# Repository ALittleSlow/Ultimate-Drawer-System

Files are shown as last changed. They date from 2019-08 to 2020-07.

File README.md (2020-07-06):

# Ultimate-Drawer-System
Intended to be the ultimate drawer system that is
* backwards-compatible with MarcElbichon's Ultimate Drawer System
* printable with FDM printing
* optimizable for anything you store in drawers
* compatible with Thingiverse's Customizer
* written for ease of improvement (which could use some improvement)

## The System
* Drawers and complementary shelving units are sized in units called "Us".
* If only one dimension is given, it is assumed to be the height and the width and depth are assumed to be 1U.
* A 1U drawer is 120 mm wide by 120 mm deep by 19 mm high.
* A 2U drawer is 120 mm wide by 120 mm deep by 39 mm high.
* Actual drawer width is 131 * Us wide - 10 mm
* Actual drawer depth is 130 * Us deep - 10 mm
* Actual drawer height is 20 * Us high - 1 mm
* A 2U shelf (or cabinet) is 131 mm wide by 130 deep by 50 mm high. (You can't (currently) make a 1U shelf.)
* Walls are 5 mm (W_t). Slots are 20 mm apart. 0.5 mm gap (g) between side wall and drawer. 
  So the height of a shelf is U.z*(19+1)+W_t*2 = 20U.z+10, width is U.x*120+5*2+1, depth is U.y*120+5*2.
* A double-wide shelf (2-U.x), to stack nicely with a single wide, should be 
  120U.z+11. With 5 mm walls, 2*(120+11)=D.x+2*W_t+2*g=D.x+11 => D.x (2U drawer width) = 262 - 11 = 251.
* A one-and-a-half wide drawer is (1.5-U.x) is 131+65.5 = 196.5-11 = 185.5.

### Inserts
Trays that fit inside basic drawers. 
Inside dimensions of 1U drawer: 131-10-1-2=118 wide, 120-2 deep, 18 high, 3 mm corner radius
Inside dimensions of 1.5U wide drawer =195.5-10-1-2 = 182.5
Inside dimensions of 2 wide drawer: 262-13 = 249
Inside dimensions of 1.5U deep drawer =195-10-2 = 183
Inside dimensions of 2 deep drawer: 260-10-2 = 247
I think the least common denominator of those widths is 0.5 mm, and 1 mm for depth. 1 mm for height also, since heights are 19, 39, 59, etc.

## Printing
Because it has all the features, is small, and is still usable, [this is a good test model](https://github.com/ALittleSlow/Ultimate-Drawer-System/blob/master/examples/shelf%200.5Wx0.5Dx2H%20clips%20noLock%20rearWeak%20frontStrong%20tol0.4.stl).

## Contributors and Contributing
This is an OpenSCAD copy then enchancement of [The Ultimate Drawer System by MarcElbichon](https://www.thingiverse.com/thing:2302575) and others to come. Contributors are welcome.

## License
This work is originally licensed under the Creative Commons Attribution-NonCommercial-ShareAlike 4.0 (CC-BY-NC-SA 4.0) but may be distributed under the GPLv3 in accordinance with the former's one-way GPLv3 compatibility declaration.

## Features
Compared to MarcElbichon's version
* Produces faithful replicas
* Add an ergonomic drawer pull
* Adds a drawer locking mechanism
* Adds a stops to help keep drawers from pulling all the way out (needs testing)
* Adds 1.5U and 2U widths and depths to the standard 1U width and 1U depth.
* The option to clip shelving units together instead of (or in addition to) screwing them together.

## Roadmap
Planned enhancements include (in no particular order)
* Drawers with dividers
* Handles for portable storage units
* Bumpers for increased ruggedness
* Sturdier versions of the drawers for increased ruggedness
* Custom label inserts
* Bosses and recesses to aid in stacking units

## Coding conventions
* Generally follow OpenSCAD conventions
* Customerizer parameters capitalized first letters with words separated by underscores.

## More information
You may find additional information, discussion, and resources at
* (Thingiverse drawer)[https://www.thingiverse.com/thing:2302575]
* (Thingiverse shelf)[https://www.thingiverse.com/thing:3796410]
* (Thingiverse MarcElbichon version)[https://www.thingiverse.com/thing:2302575]
* (Parametric drawers by _WG_)[https://www.thingiverse.com/thing:2552468]

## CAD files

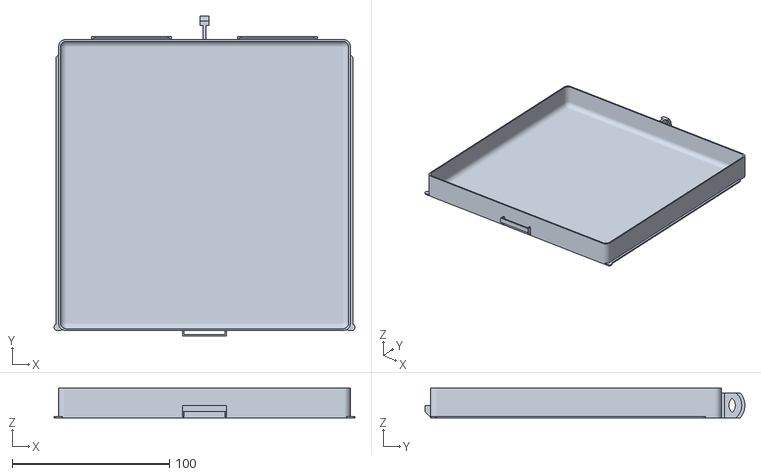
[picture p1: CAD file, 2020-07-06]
examples/drawer 1.5Wx1.5Dx1H ergo catch lock.stl
191.5 x 203.5 x 19.0

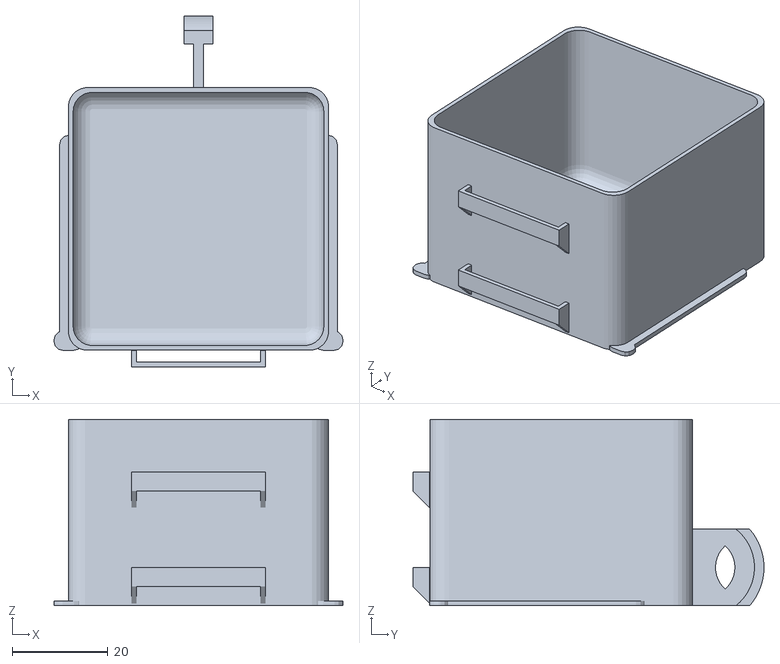
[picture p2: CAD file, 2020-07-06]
examples/drawer 0.5Wx05.Dx2H ergo catch noLock.stl
60.5 x 73.5 x 39.0

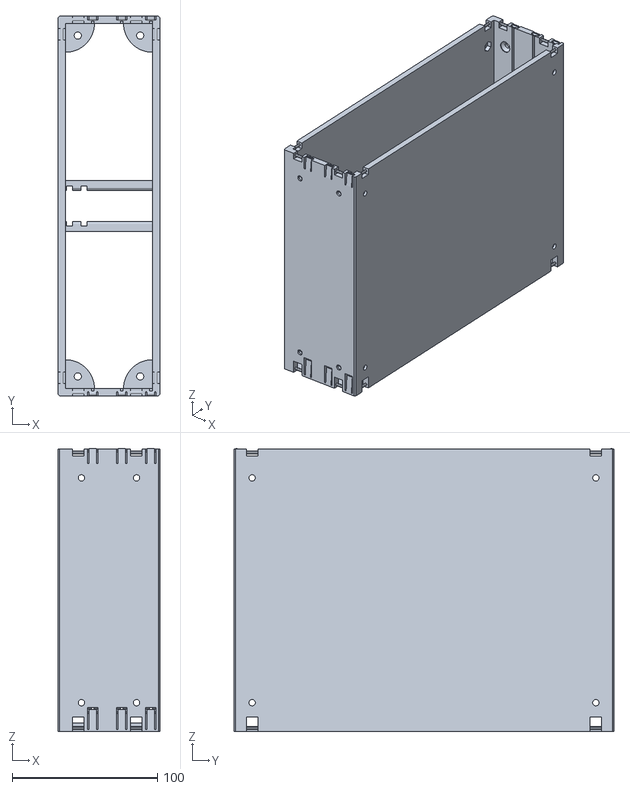
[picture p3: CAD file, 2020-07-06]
examples/shelf Becky's Jewelry Box 2x1.5x3.stl
70.0 x 262.0 x 195.4

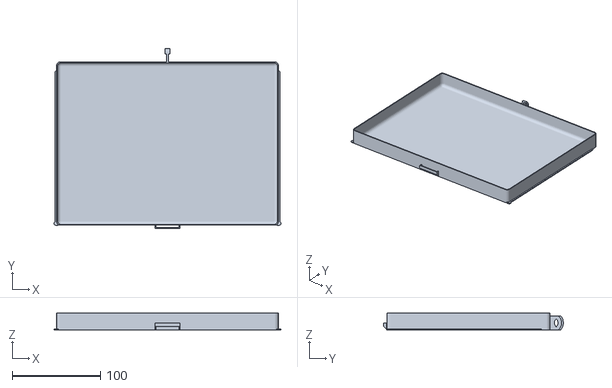
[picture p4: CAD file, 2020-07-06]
examples/drawer 1.5Wx2Dx1H ergo catch lock.stl
257.0 x 203.5 x 19.0

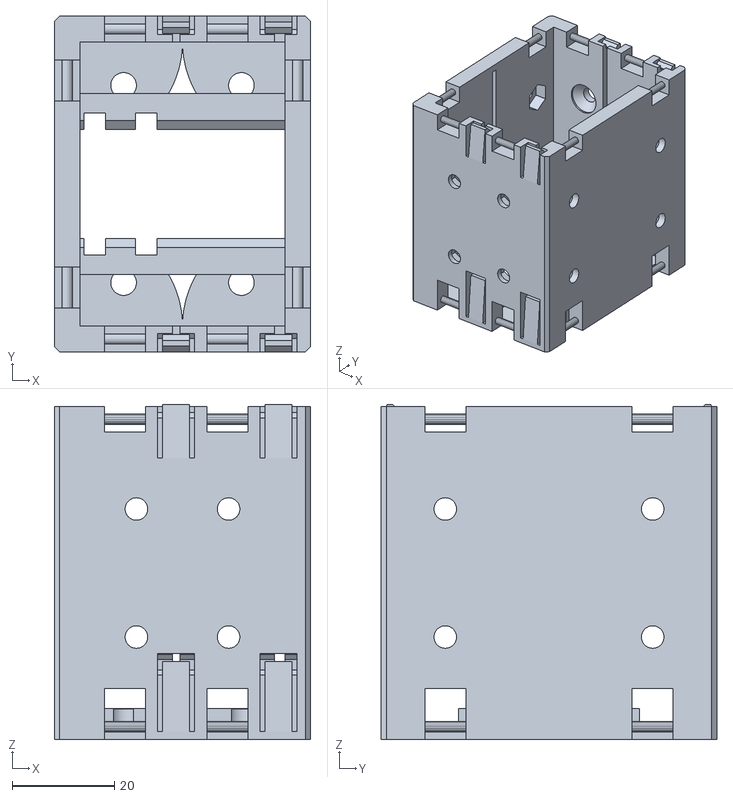
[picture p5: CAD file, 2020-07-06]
examples/Shelf Test Mini Model v1.1.stl
50.0 x 65.5 x 65.4

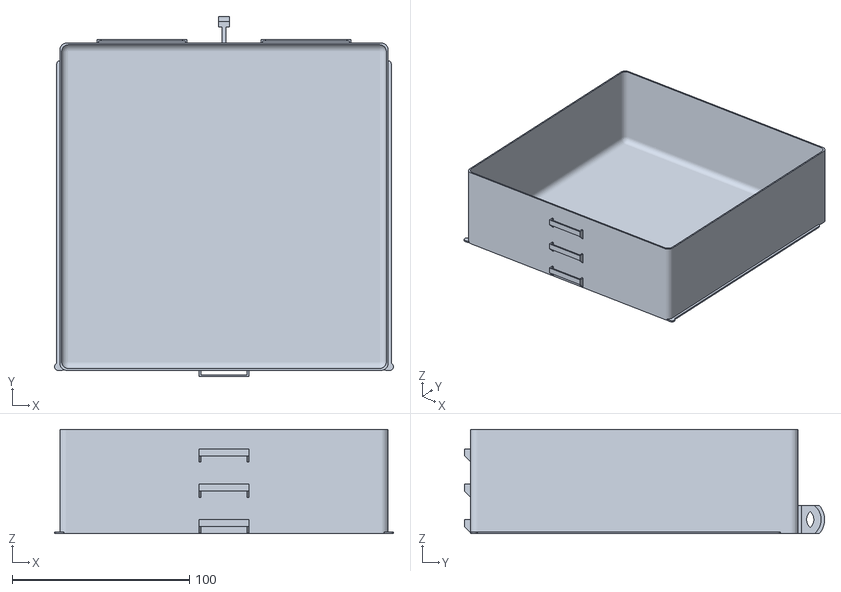
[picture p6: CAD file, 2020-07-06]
examples/drawer 1.5Wx1.5Dx3H ergo catch lock.stl
191.5 x 203.5 x 59.0

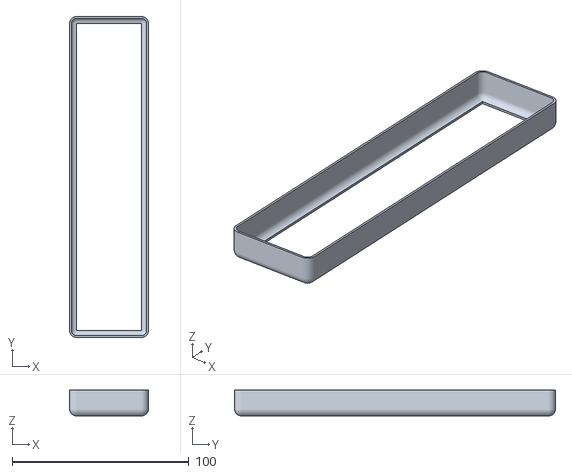
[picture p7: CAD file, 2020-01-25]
examples/insert 45x118 x15for eye glasses.stl
44.6 x 181.6 x 14.6

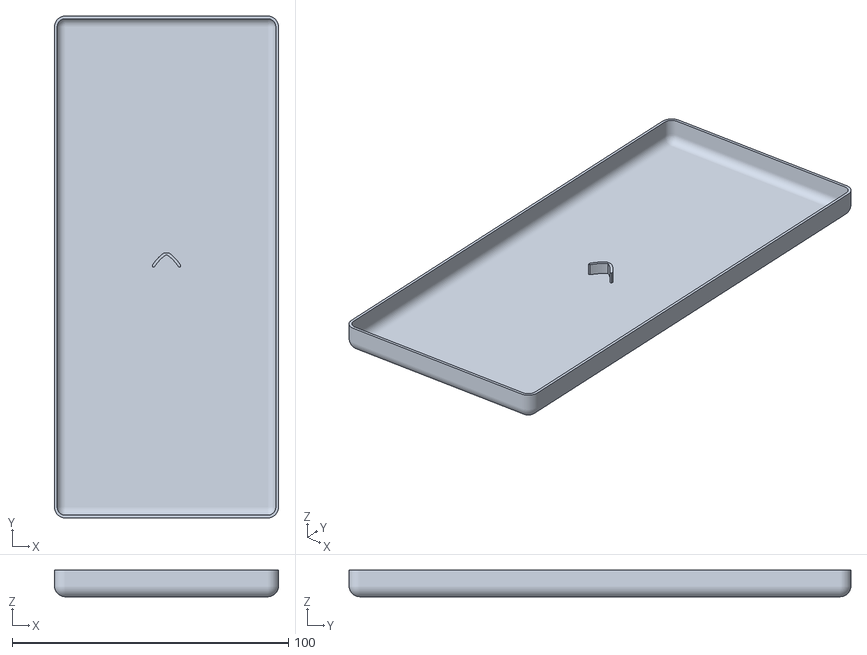
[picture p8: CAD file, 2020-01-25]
examples/insert 182x81.5x10 pliers.stl
81.1 x 181.6 x 9.60

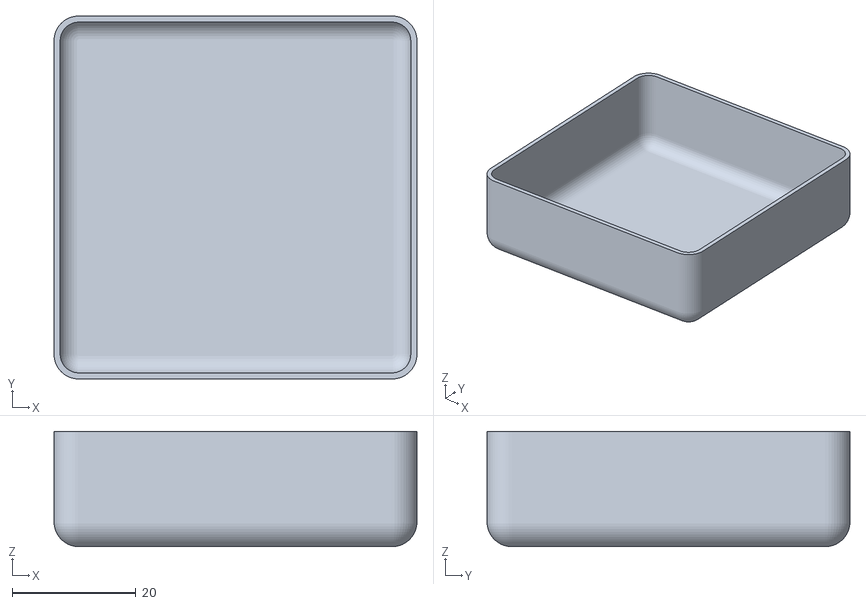
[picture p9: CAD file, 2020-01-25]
examples/insert 59x59x19 for 1x1x1 or 1x1x2 drawer.stl
58.6 x 58.6 x 18.6

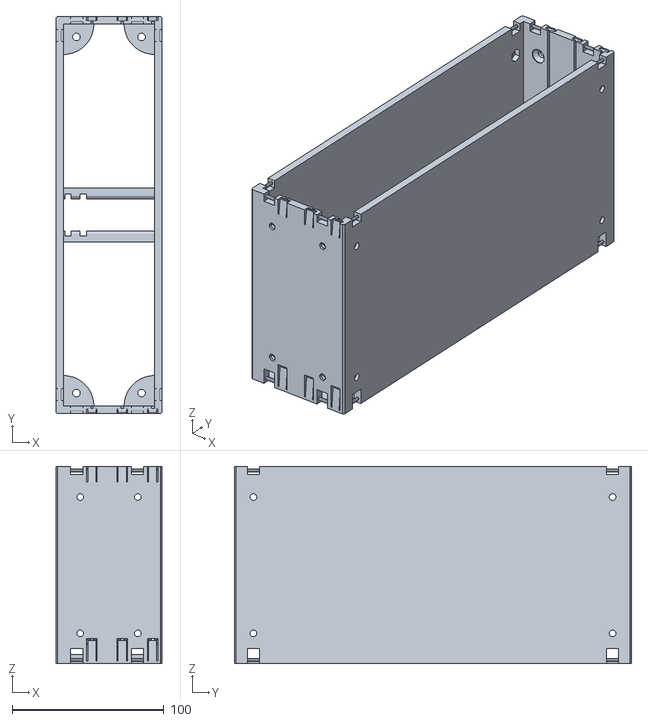
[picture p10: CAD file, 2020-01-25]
examples/shelf Becky's Jewelry Box shelf 2x1x3.stl
70.0 x 262.0 x 130.3

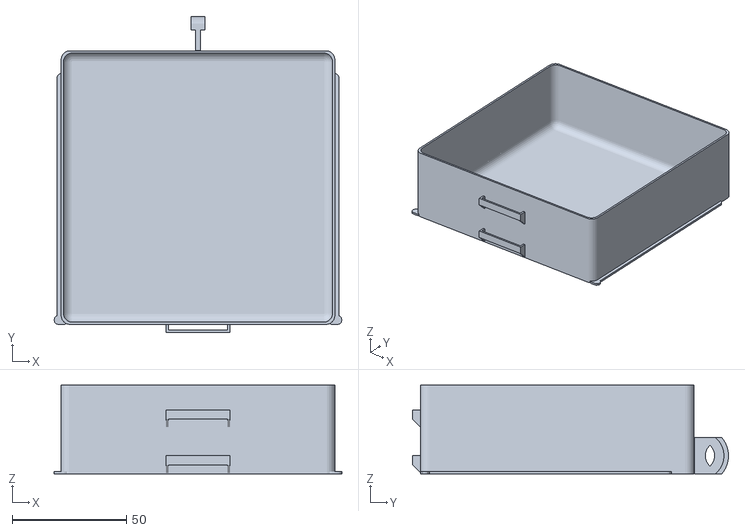
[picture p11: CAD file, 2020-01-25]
examples/drawer 1Wx1Dx2H ergo catch lock noLabel.stl
126.0 x 138.5 x 39.0

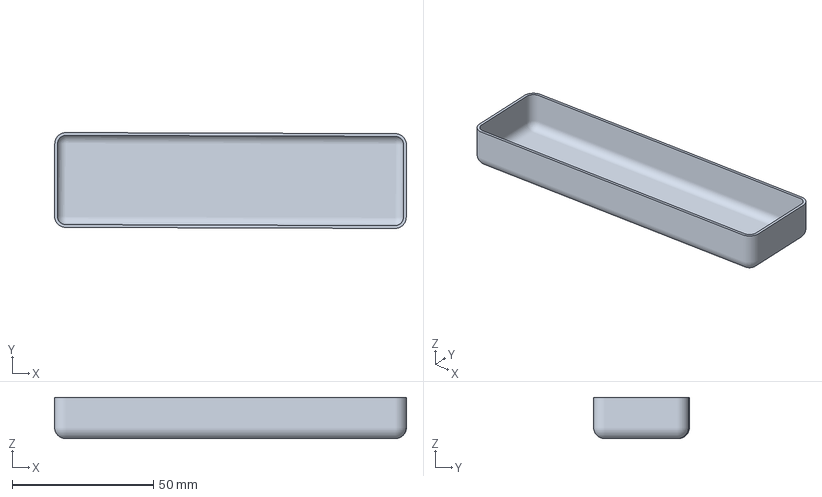
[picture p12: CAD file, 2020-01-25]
examples/insert Elmers Glue Stick 40g.3mf
124.7 x 34.0 x 14.6 mm

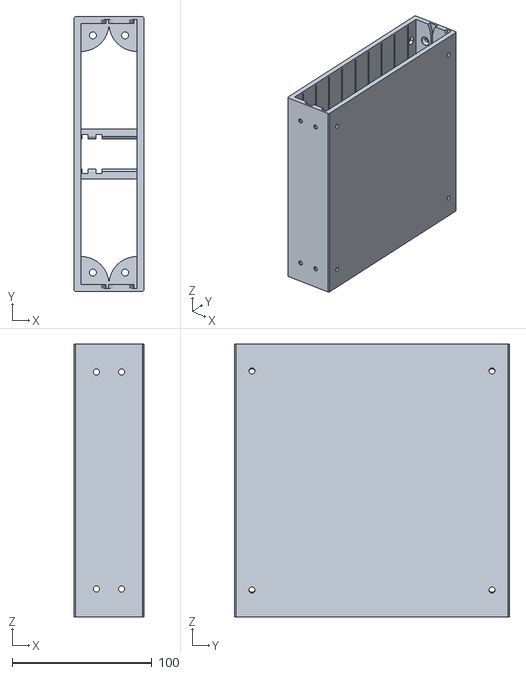
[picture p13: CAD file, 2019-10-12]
examples/shelf 2U1.5D1.5W.stl
50.0 x 196.5 x 195.0

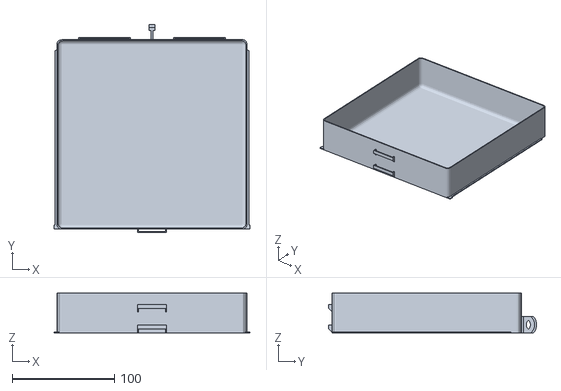
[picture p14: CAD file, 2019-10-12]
examples/drawer 1.5Wx1.5Dx2U ergo catch lock.stl
191.5 x 203.4 x 39.0

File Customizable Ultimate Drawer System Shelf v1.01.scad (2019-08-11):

// Customizable Ultimate Drawer System Shelf
// Remixed from MarcElbichon's Ultimate Drawer System https://www.thingiverse.com/thing:2302575 (CC-BY 4.0)
// Copyright (C) 2019 by Brian Alano (and possibly others)
// Licensed under the Creative Commons Attribution-NonCommercial-ShareAlike 4.0 (CC-BY-NC-SA 4.0) and
// sharable under the GPLv3.

/* Release Notes
 * Version 1.01 - bugfix release
 * Fix bug in clips where variable was undefined
 * Remove non-functional "retaining clip" parameter
 */ 

/* Design notes
// width is x dimension, across the face of the drawer
// depth is y dimension, front to back of the drawer
// height is z dimension
*/

/* Coding Style Guide 
 * User parameters and modules use underscores between words.
 * Other variable names use camel case.
 * Separate features into their own modules if they are more than a couple lines long.
 * All dimensions should be assigned to variables, usually global ones so they can be found easily.
 * Keep local modules local.
 * Keep local variables local.
 * Maintain Thingiverse Customizer compatibility.
 * Maintain backwards compatibility with MarcElbichon's Ultimate Drawer System 
   (https://www.thingiverse.com/thing:2302575). This means a 1Ux1Ux1U drawer 
   made with this program will work in MarcElbichon's shelf. 
 * Whereas normally an "include" file would handle parameters that are reused among code, 
   Customizer can't handle that. Instead we'll have to manually paste in the include file whenever it changes.
*/

// Walls are 5 mm (W_t). Slots are 20 mm apart. 0.5 mm gap (g) between side wall and drawer. 
// So the height of a shelf is U.z*(19+1)+W_t*2 = 20U.z+10, width is U.x*120+5*2+1, depth is U.y*120+5*2.
// A double-wide shelf (2-U.x), to stack nicely with a single wide, should be 
// 120U.z+11. With 5 mm walls, 2*(120+11)=D.x+2*W_t+2*g=D.x+11 => D.x (2U drawer width) = 262 - 11 = 251.
// A one-and-a-half wide drawer is (1.5-U.x) is 131+65.5 = 196.5-11 = 185.5.
//which part to render

//TO-DO add stacking aligners

/* [General] */
// which part of the shelf to render. Customizer will generate one of each.
part="shelf"; //[shelf, clip, rear_lock] 
//one U wide is 131 mm. Total width is 131*U.
U_Wide=1; //[1,1.5,2]
//one U high 20 mm for the drawer and 10 mm for the shelf, or 30 mm. In general, total height is 20*U + 10.
U_High=2; //[2:15]
//one U deep is 130 mm. Total depth is 130*U.
U_Deep=1; //[1,1.5,2]
/* [Features] */
// enable using clips to hold shelves together [not implemented]
clips="no"; // [yes, no]
// add a drawer locking mechanism in the rear?
rear_lock="no"; // [yes, no]
/* [Rendering] */
// 3d printing layer height (optimizes some spacing
layer_height = 0.2; // [0.1:0.05:0.3]
// set this to printing before pressing Create Thing for best results
orientation = "printing"; // [printing, viewing]
/* [Advanced] */
/* [Hidden] */
hole_diameter=5;
backThickness=2;

//shelfWidth = 131;
//shelfDepth = 130; //z direction
wallThickness = 5;
shelfUnit = [130, 131, 30];
shelf = [shelfUnit.x * U_Deep, shelfUnit.y * U_Wide, (shelfUnit.z - wallThickness*2) * U_High + wallThickness*2];
shelfCut = [shelf.x, shelf.y - wallThickness*2, shelf.z - wallThickness*2];
/* We want 1 - 2W shelf to be the same dimension as 2 - 1W shelves. This means the drawer will be wider than 120*2 since there are no walls in between. Similarly, we want 2 - 1.5W shelves to be the same dimension as 3 - 1W shelves.
    so
    1W = 131 shelf, 131-10 = 121 cut, 131-11 = 120 drawer
    1.5W=131+65.5=196.5shelf,186.5cut,196.5-11=185.5drawer
    2W = 262 shelf, 262-10 = 252 cut, 262-11 = 251 drawer
    1D = 130 shelf, 130  = 130 cut, 130-10 = 120 drawer
    2D = 260 shelf, 260  = 260 cut, 260-10 = 250 drawer
    1U = (30-walls)*U+walls=30 shelf, 30-10  =  20 cut, 30-10-1=  19 drawer
    2U =  50 shelf, 50-10  =  40 cut, 50-10-1=  39 drawer
    W=
    Front to back we can do the same thing, though it's less useful.
   The same does not apply to the height. 2 - 2U shelves will be 100mm, but 1 - 4U shelf is only 90mm.
*/    

tolerance = 0.2;
slotSpacing = shelfUnit.z - wallThickness*2;

rearLockSlot = [3.5, 26, 8]; // copied from the drawer as a reference dimension
rearLockWallThickness = 1;
// tab is "tongue" part of the rear latch mechanism
tabSize = [1.5, rearLockSlot.y - rearLockWallThickness*2 - tolerance,
    rearLockSlot.z]; 
// bar is the main part of the rear_lock mechanism
barSize = [6.5 - tolerance, tabSize.y, slotSpacing];
snapHead = 4.4;
snapInset = 3;

holeOffset = [20, 12.5, 16]; // positions of the holes from the outside edges of the respective sides
slotBottomWidth = 1.25;
slotSideLength = shelfCut.x - 18;
slotTaperLength = 15;
clipCut = [10, 5, 8];
clip_bar_diameter = 2;
clipThickness = 1.2;
slotDepth = 3;

// Convenience definitions
X = [1, 0, 0]; // x-coordinate unit vector 
Y = [0, 1, 0]; // y-coordinate unit vector 
Z = [0, 0, 1]; // y-coordinate unit vector 
epsilon = 0.01; // mainly used to avoid non-manifold surfaces

$fa=1;
$fs=.4;


//module shelf() {
//    module add() {
//    }
//    module subtract() {
//    }
//    difference() {
//    }
//
//}

// the spacing between drawings is 20, or unit.z + 1. so a 1U drawer is 19, a 2U drawer is 39, etc.
function zU(u) = slotSpacing * u - 1;

// extrude a given length of rear latch bar
module bar_stock(h) {
     reflect(Y) // double the profile half
        linear_extrude(h) 
        polygon([
            [-epsilon, epsilon], [-epsilon, -barSize.y/2],
            [1.35, -barSize.y/2],
            [barSize.x/2, -(barSize.y/2 - barSize.x/2 + 1.35)],
            [barSize.x - 1.35, -barSize.y/2],
            [barSize.x, -barSize.y/2],
            [barSize.x, epsilon]
        ]);
}

module shelf() {
    //yOffset = 13; // for the front latch. Needs work. wide enough to clear any drawer pulls. Otherwise as narrow as possible.
    topSlotSpacing = 20.17; // measured from the original
 
    // h - height of inside of shelf
    // w - weidth of inside of shelf

    // make one of four wall mount plates for the back wall
    module back() {
        r= slotSpacing;
        offset=holeOffset.z - hole_diameter/2;
        module add() {
            translate([wallThickness, wallThickness])
                rotate_extrude2(angle=90)
                square(size=[r, backThickness]);
        }
        module subtract() {
            translate([offset, offset]) 
                cylinder(d=hole_diameter, h=backThickness*4, center=true);
        }
        rotate([0, -90, 0]) // move it from the XY to YZ plane
            difference() {
                add();
                subtract();
        }
    }

    module countersink() {
        counterbore_h = 0.5;
        countersink_h = 2.3;
        counterbore_d = 9;
        through_d = 4.4;
        // counterbore
        translate([0, 0, -epsilon]) cylinder(d=counterbore_d, h=counterbore_h + epsilon*2);
        // countersink
        translate([0, 0, counterbore_h]) cylinder(d1=counterbore_d, d2=through_d, h=countersink_h);
        // through
        translate([0, 0, counterbore_h + countersink_h - epsilon]) cylinder(d=through_d, h=wallThickness);
    }

    module hex_hole() { 
        hex_w = 7.4;
       
        hex_h = 3.5;
        through_h = 1.5;
        through_d = 4.4;
        // hex head
        boxWidth = hex_w/1.75;
        translate([0, 0, hex_h/2-epsilon])
            for (r = [-60, 0, 60])
                rotate([0,0,r])
                cube([boxWidth, hex_w, hex_h+epsilon*2], true);
        // through hole
        translate([0, 0, hex_h - epsilon])
            cylinder(d=through_d, h=through_h + epsilon*2);
    }
    // make the slot and catch that the rear slot slides into
    module rear_slot() {
        blockSize = [barSize.x, barSize.y + tabSize.y/2, shelfCut.z];
        
        // add a block of material to enclose the slot
        module add() {
            translate([-shelf.x/2 + blockSize.x/2, 0, 0])
                cube(blockSize, center=true);
        }
        
        module subtract() {
            // detents for the snap
            reflect(Y) {
                translate([-shelf.x/2 + blockSize.x/2 , barSize.y/2]) {
                    // one to hold it up
                    translate([0, 0, shelf.z/2 - slotSpacing/2 + snapHead/2])
                        cube([blockSize.x + epsilon *2, snapHead, snapHead], center=true);
                    // one to hold it down
                    translate([0, 0, shelf.z/2 - slotSpacing + snapHead/2])
                        cube([blockSize.x + epsilon *2, snapHead, snapHead], center=true);
                }
            }
        }
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

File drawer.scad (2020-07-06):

// Customizable Ultimate Drawer System Drawer
// Remixed from MarcElbichon's Ultimate Drawer System https://www.thingiverse.com/thing:2302575 (CC-BY 4.0)
// Copyright (C) 2019 by Brian Alano (and possibly others)
// Licensed under the Creative Commons Attribution-NonCommercial-ShareAlike 4.0 (CC-BY-NC-SA 4.0)

/* Release Notes 
 * Version 1.1
 * Made label slots optional, and removed them entirely for 0.5U wide drawers.
 * Added 0.5U wide and 0.5U deep options
 */
 
/* Design notes
// width is x dimension, across the face of the drawer
// depth is y dimension, front to back of the drawer
// height is z dimension
*/

/* Coding Style Guide 
 * User parameters and modules use underscores between words.
 * Other variable names use camel case.
 * Separate features into their own modules if they are more than a couple lines long.
 * All dimensions should be assigned to variables, usually global ones so they can be found easily.
 * Keep local modules local.
 * Keep local variables local.
 * Maintain Thingiverse Customizer compatibility.
 * Maintain backwards compatibility with MarcElbichon's Ultimate Drawer System 
   (https://www.thingiverse.com/thing:2302575). This means a 1Ux1Ux1U drawer 
   made with this program will work in MarcElbichon's shelf. 
*/

/* [Size] */
// units wide (actual drawer width is 131*U_wide - 10)
U_wide=1; // [0.5, 1, 1.5, 2]
// units deep (actual drawer depth is 130*U_deep - 10)
U_deep=1; // [0.5, 1, 1.5]
// units high (actual drawer height is 20*U_high - 1)
U_high=3; // [1:15]

/* [Features] */
// Include slots for labels? 
labels = "yes"; //[yes, no]
// What kind of drawer pull?
pull_style = "original"; // [original, ergonomic, ring]
// the flange is what keeps the drawer in the slot. "catch" leaves a bump for holding the drawer in the a shelf with snaps. 
flange_style = "normal"; // [normal, catch, none]
// include slots on the back of the drawer for the locking mechanism
rear_lock_slot = "no"; // [yes, no]

/* [Hidden] */
// utility variables
epsilon = 0.01;
$fs=1;
$fa=5;

drawerUnit=[120, 120, 19];
shelfPadding=[11, 10, 1];

wallThickness = 1;
shelfUnit = [131, 130, 30];
shelf = [shelfUnit.x * U_wide, shelfUnit.y * U_deep, (shelfUnit.z - wallThickness*2) * U_high - wallThickness*2]; // reference dimension from shelf .scad file.
echo("shelf dimensions", shelf);
drawer = [shelf.x - shelfPadding.x, shelf.y - shelfPadding.y, shelf.z - shelfPadding.z];
echo("drawer dimensions", drawer);

cornerR = 4;
cornerD = cornerR * 2;
flange = [flange_style == "catch" 
    ? 3*0.6 
    : flange_style == "none" 
        ? 0
        : 3, d_to_y(U_deep)-shelfPadding.y, 1];
flangeR = flange.x - epsilon;
flangeD = flangeR * 2;
catchFlange = 10;
pullD = 24.38;
pull = [2, pullD/2 + 2.8, 16];
label = [51, 2, 16];
labelSlot = [49, 1, 15];
labelWindow = [46, 1, 14];
catch = [3, 4, flange.z];
rearLockSlot = [26, 3.5, 8];
includeLabels = labels == "yes" && U_wide > 0.5;

// the spacing between drawings is 20, or drawerUnit.z + 1. so a 1U drawer is 19, a 2U drawer is 39, etc.
//FIXME replace with drawer[]
//FIXME put lock on bottom, not top.
function u_to_z(u) = (drawerUnit.z + shelfPadding.z) * u - shelfPadding.z;
function w_to_x(w) = (drawerUnit.x + shelfPadding.x) * w - shelfPadding.x;
function d_to_y(d) = (drawerUnit.y + shelfPadding.y) * d - shelfPadding.y;

module drawer(U_wide = U_wide, U_deep = U_deep, U_high = U_high, includeLabels = includeLabels) {
    module add() {
        // main body
        linear_extrude(u_to_z(U_high))
            roundtangle(width=w_to_x(U_wide), length=d_to_y(U_deep), radius=cornerR);
        // flanges
        reflect([1, 0, 0]) {
            linear_extrude(flange.z) 
            translate([w_to_x(U_wide)/2, -(d_to_y(U_deep) - flange.y)/2]) {
                roundtangle(flange.x*2, flange.y, flangeR);
            }
            translate([w_to_x(U_wide)/2, -(d_to_y(U_deep) - catch.y)/2, 0]) {
                linear_extrude(flange.z) roundtangle(catch.x*2, catch.y, flangeR);
            }
        }

        // pull
        translate([0, d_to_y(U_deep)/2, pull.z/2]) pull(style=pull_style);

        // label holders (positive part)
        if (includeLabels) labels("add");

        // rear lock pockets
        if (rear_lock_slot == "yes")
            for(j = [1:U_high])
                translate([0, -d_to_y(U_deep)/2, u_to_z(j)]) 
                    rearLockSlot();
    }
    
    module subtract() {
        // main cut, minus fillets
        cut = [w_to_x(U_wide) - wallThickness*2, d_to_y(U_deep) - wallThickness*2, u_to_z(U_high) - wallThickness - cornerR];
        translate([0, 0, u_to_z(U_high) - cut.z + epsilon]) 
            linear_extrude(cut.z + epsilon) roundtangle(cut.x, cut.y, cornerR);
        // fillet cut
       translate([0, 0, u_to_z(U_high) - cut.z]) 
            minkowski() {
                cube([cut.x - cornerD, cut.y - cornerD, epsilon], center=true);
                sphere(d=cornerD);
            }
        // label holders (positive part)
        if (includeLabels) labels("subtract");

    }
     
    difference() {
        add();  
        subtract();
    }
}

module labels(mode="add") {
    module add() {
        for (i = [1, -1]) {
            translate([w_to_x(U_wide)/4*i, (d_to_y(U_deep) + label.y)/2 - epsilon, label.z/2]) cube([label.x, label.y + epsilon, label.z], center=true);
        }
    }
    
    module subtract() {
        for (i=[1, -1]) {
            // label cuts
            translate([w_to_x(U_wide)/4*i, d_to_y(U_deep)/2 + labelSlot.y/2, labelSlot.z/2 + (label.z - labelSlot.z) + epsilon])
                cube(labelSlot, center=true);
            translate([w_to_x(U_wide)/4*i, d_to_y(U_deep)/2 + label.y - wallThickness/2, labelWindow.z/2 + (label.z - labelWindow.z) + epsilon])
                cube(labelWindow, center=true);
        }
    }
    
    if (mode=="add") add(); else subtract();
}


module pull(style) {
    // drawer pull
    module original() {
        intersection() {
           translate([0, pull.y/2 - epsilon]) cube([pull.x, pull.y + epsilon, pull.z], center = true);
           translate([0, pull.y - pullD/2]) rotate([0, 90, 0]) cylinder(d=pullD, h=pull.x, center = true);
        }
    }

    module ergonomic() {
        difference() {
            original();
            translate([0, pull.y - pullD/2]) rotate([0, 90, 0]) {
                intersection() {
                    cylinder(d=pullD/2, h=pull.x+epsilon*4, center = true);
                    translate([0, pullD/3]) cylinder(d=pullD/2, h=pull.x+epsilon*4, center = true);
                }
            }
        }
        scale([3, 1, 1]) difference() {
            original();
            translate([0, pull.y - pullD/2]) rotate([0, 90, 0]) cylinder(d=pullD-pull.x*2, h=pull.x+epsilon*2, center = true);
        }
    }

    if (style == "original") original();
    if (style == "ergonomic") ergonomic();
}

module rearLockSlot() {    
    module half() {
        translate([rearLockSlot.x/2, -rearLockSlot.y, -drawerUnit.z + rearLockSlot.z/2]) 
        {
            cube([wallThickness, rearLockSlot.y, rearLockSlot.z/2]);
            rotate([0, 90, 0])
                linear_extrude(wallThickness) 
                polygon([[0, 0], [rearLockSlot.y, rearLockSlot.y], [0, rearLockSlot.y]]);
        }
        translate([0, -rearLockSlot.y, -drawerUnit.z + rearLockSlot.z/2]) 
            cube([rearLockSlot.x/2, wallThickness, rearLockSlot.z/2]);
    }
    
    module add() {
        for(i=[0, 1]) 
            mirror([i, 0, 0]) half();
    }
    add();
//    half();
}


/* render both the child object and its mirror 
    usage: otherwise operates just like mirror()
*/
module reflect(v) {
    children();
    mirror(v) children();
}


module roundtangle(width, length, radius) {
    minkowski() {
                square([width - radius*2, length - radius*2], center=true);
                circle(r=radius);
            }
}

drawer();
//pull(style="ergonomic");
//rear_lock();

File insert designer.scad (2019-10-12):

/* insert designer 
 let's you set up inserts for a whole drawer
 */
 use <drawer.scad>;
 use <insert.scad>;
 
 U_wide = 1;
 U_deep = 1;
 U_high = 1;
 labels = "no";
 grid_size = [3,3];
 inserts = [[1,1], [2, 1]];
 /* [Hidden] */
 includeLabels = labels == "yes" ? true : false;
 drawer(U_wide = U_wide, U_deep = U_deep, U_high = U_high, includeLabels = includeLabels);
 
module main() {
    for (insert=inserts) {
        translate([drawer.x/2, 1]) insert([insert.x, insert.y, U_high/2]);
    }
}
 main();
 

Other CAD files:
examples/insert 59x118x17, 0.10 tolerance for 1x1 drawer.stl
examples/insert 59x59x10 for 1x1 drawer.stl
examples/insert 118x118x10 round island 45-20 for 1x1 drawer.stl
examples/shelf 0.5Wx0.5Dx2H clip lock rearMedium frontMedium.stl
insert.scad
Customizable Ultimate Drawer System Shelf v1.0.scad
archive/Customizable Ultimate Drawer System Drawer v1.0.scad
archive/Customizable Ultimate Drawer System Shelf v1.0.scad
archive/Customizable Ultimate Drawer System Shelf v1.01.scad
archive/Customizable Ultimate Drawer System Shelf v1.1.scad
examples/clip 0.3 tolerance.stl
examples/drawer 0.5Wx05.Dx1H ergo catch noLock.stl
examples/drawer 1U ergo catch lock noLabel.stl
examples/drawer 1U ergo catch lock.stl
examples/drawer 1U ergo.stl
examples/drawer 1U noFlange noLabel.stl
examples/foot v1.1.stl
examples/insert 29.5x29.5x10 for 1x1 drawer.stl
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

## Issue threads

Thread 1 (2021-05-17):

Regarding labels

NameOfTheDragon, 2021-05-17:
I've tried a number of drawer systems including some of my own design. What I have found is that those little bits on the front designed to hold a label do not work too well in practice. They tend to not hold the label very firmly and it is easy to brush the top of the label, perhaps while removing an adjacent drawer, which pulls it right out. They are also not very tolerant of undersized labels.

After some experimentation I settled on a different design that I used in my component drawers, where the label is fully enclosed on all 4 sides, as in the photo. The label holder becomes an integral part of the front face of the drawer.

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

To implement this design,

- the front face of the drawer is thickened somewhat (side benefit - stronger handle).
- A slot is punched down from the top. The slot is the full width of the label plus a bit to allow for easy insertion. Chamfers can be added at the top to make a "funnel" to guide the label in.
- A rectangular window is punched from the front so that the label can be seen.

The label then drops in from the top and is very hard to remove by accident, but easy to remove deliberately. I have found that this design also prints more reliably and does not require cleanup after printing. Generous margins can be used which allows for a good tolerance in the size of labels. It is hard to cut labels with millimeter accuracy!

There's a CAD model of my design at https://a360.co/3buz332 - I would love to see something like this included in the Ultimate Drawer System.

ALittleSlow, 2021-05-18:
Great idea. I've experienced the same issues you describe with the existing design.

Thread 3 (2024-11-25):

shelf label is not attached well to main body

cheesehead544, 2024-11-25:
When printing the shelf i noticed the bottom of the label holder was slightly detached  from the main body. For a quick fix i changed drawerlength/2 to drawerlength/2.001 at line 129. i attached some screenshots but it's kinda hard to make out clearly. Could this change be implemented or is there a better way to do this? i'm not hugely familiar with openscad but this gap doesn't seem intentional to me.
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

cheesehead544, 2024-11-25:
i did customize the lenght and width to values not available in the customizer but setting them to back to 1 does not solve this issue. changing extendLabels or scaleLabels also does not change the issue

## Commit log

2019-08-07 Initial upload
    [Customizable Ultimate Drawer System Drawer v1.0.scad]
2019-08-07 a couple examples
    [1.5Wx1.5Dx2U ergo catch drawer lock.stl, 2U1.5D1.5W shelf.stl]
2019-08-08 Customizer tweaks
    [Customizable Ultimate Drawer System Drawer v1.0.scad, Customizable Ultimate Drawer System Shelf v1.0.scad]
2019-08-09 added inserts model with examples
    [1U errgo drawer.stl, 45.0x118x18 insert.stl, 79.0x118x18 insert.stl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]
2019-08-11 Some bugfixes and more examples
    Bug with making clip pockets in shelf fixed. Meaningless parameter removed.
    [1.5Wx1.5Dx2U clip lock shelf.stl, 45.0x118x18 insert.stl, 45.0x182x10 insert.stl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]
2019-10-12 version 1.1
    * Fixed error where hex and countersink holes were on the wrong sides (thanks, malikai!)
    * Optional front and rear snaps to hold drawers in and keep them from falling out
    * Added a foot that presses into the bottom holes
    * Fixed bug in bottom hole placement
    * Fixed rib in top interefers with top front clips at 1.5U W and 0.5U wide
    * Added 0.5U wide, and 0.5U deep, primarily for test
    * Made screw holes optional
    * Optional top and bottom ribs (not needed if you are doing infill)
    * Version 1.01 - bugfix release
    * Fix bug in clips where variable was undefined
    * Remove non-functional "retaining clip" parameter
    [0.5Wx0.5Dx2H clip lock rearMedium frontMedium shelf.stl, 1U errgo catch lock drawer.stl, 1Wx1Dx1U clip lock rearMedium frontMedium shelf.stl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]
2019-10-12 examples cleanup
    [1.5Wx1.5Dx2U ergo catch drawer lock.stl, 2U rear lock.stl, 2U1.5D1.5W shelf.stl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]
2020-01-25 updated insert and more examples
    tweaked some features in the insert module and added more examples
    [drawer 1Wx1Dx2H ergo catch lock noLabel.stl, insert 182x81.5x10 pliers.stl, insert 45x118 x15for eye glasses.stl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]
2020-07-06 misc fixes
    [Shelf Test Mini Model v1.1.stl, drawer 0.5Wx05.Dx2H ergo catch noLock.stl, drawer 1.5Wx1.5Dx1H ergo catch lock.stl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]
